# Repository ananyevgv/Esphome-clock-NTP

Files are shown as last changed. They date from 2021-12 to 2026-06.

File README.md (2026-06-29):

# ⏰ Умные часы с автоматической синхроизацией времени

[][license]
[][esphome-release]

[license-shield]: https://img.shields.io/static/v1?label=License&message=MIT&color=orange&logo=license
[license]: https://opensource.org/licenses/MIT
[esphome-release-shield]: https://img.shields.io/github/v/release/esphome/esphome?label=ESPHome&color=green&logo=esphome
[esphome-release]: https://GitHub.com/esphome/esphome/releases/

**Семейство умных часов** с синхронизацией времени, автоматической регулировкой яркости и расширенным функционалом — от датчиков до интернет-радио.

---

## 📸 Фотогалерея

| Версия 1 | Версия 2 | Версия 3 | Версия 4 |
|---|---|---|---|
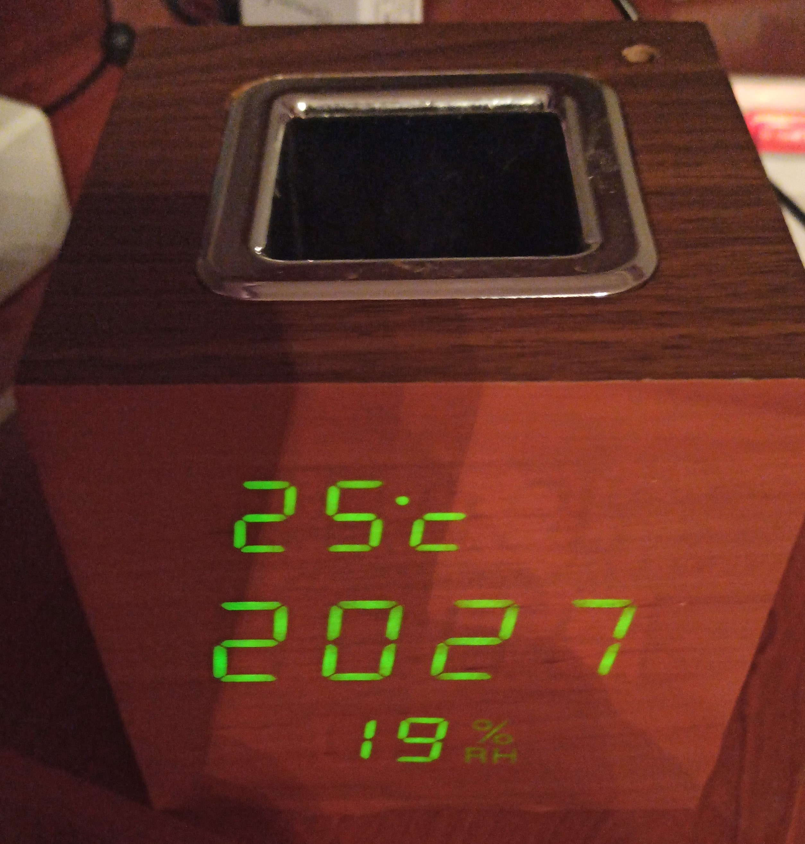
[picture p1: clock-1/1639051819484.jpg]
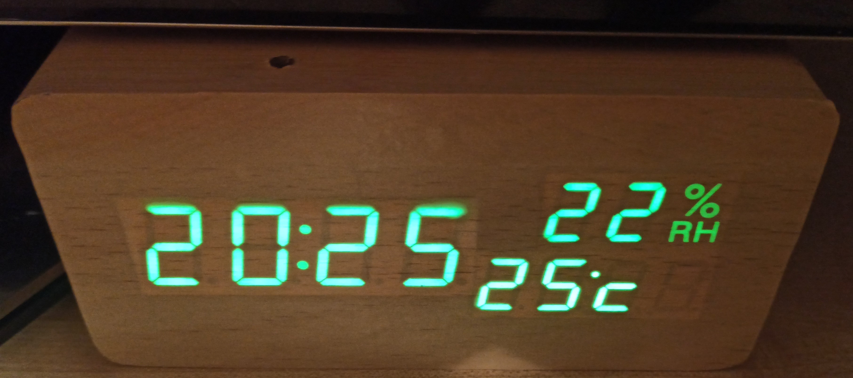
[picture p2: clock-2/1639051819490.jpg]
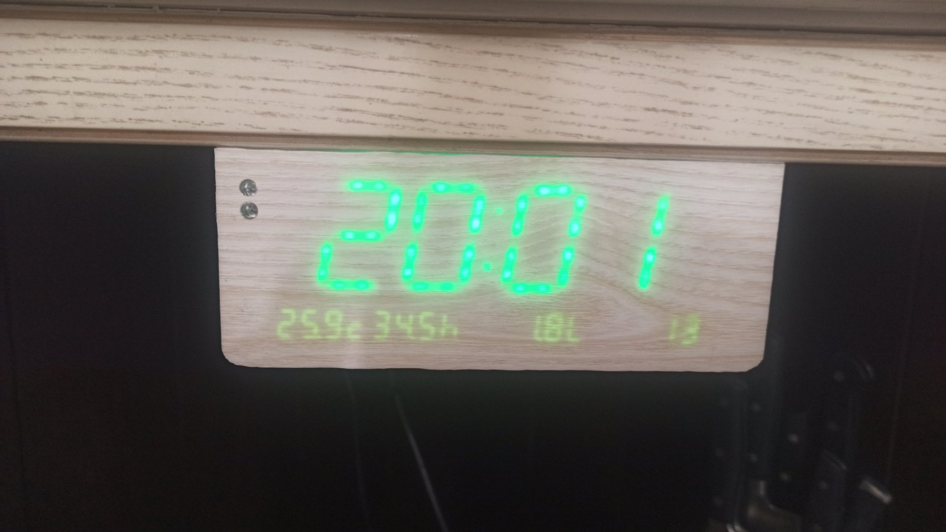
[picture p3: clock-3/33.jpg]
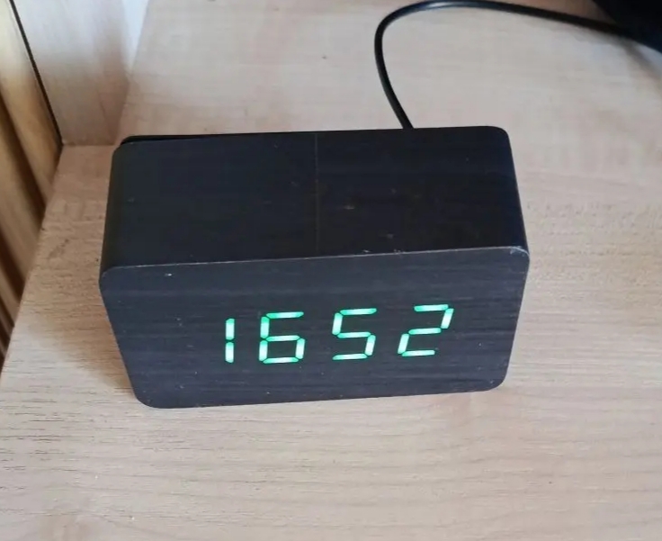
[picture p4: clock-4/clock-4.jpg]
|  |  |  |  |

---

## 🎯 Концепция

> **Всё в одном устройстве.**  
> Избавляемся от множества отдельных датчиков — все функции объединены в настольных часах.

Китайские готовые часы часто имеют дисплеи, установленные "вверх ногами".

---

## 📦 Версии

### 🔵 Версия 1
**Базовые часы + датчики + радио**

- ⏰ Синхронизация времени (NTP)
- ☀️ Автоматическая регулировка яркости
- 🌡️ Температура и влажность
- 💨 Качество воздуха
- 🌅 Положение солнца над горизонтом
- 📻 Интернет-радио 

**Дисплей:** 2 × TM1637 (7-сегментные, общий анод)  
*Особенность:* 5-й и 6-й разряды используются для индикации влажности

---

### 🟢 Версия 2
**Часы + датчики**

- ⏰ Синхронизация времени (NTP)
- ☀️ Автоматическая регулировка яркости
- 🌡️ Температура и влажность
- 🏠 Температура пола
- 📊 PZEM AC (мониторинг энергопотребления)
- 📡 ИК-пульт (управление ТВ)
- 🌡️ Атмосферное давление
- 🌅 Положение солнца над горизонтом

**Дисплей:** 3 × TM1637 (7-сегментные, общий анод)  
*Особенность:* 3-й разряд и DP 3-го модуля отображают значок влажности

---

### 🟡 Версия 3
**Часы для кухни**

- ⏰ Синхронизация времени (NTP)
- ☀️ Автоматическая регулировка яркости
- 🌡️ Температура и влажность
- 🏠 Температура пола
- 💧 Расход и температура фильтрованной воды
- 📡 ИК-пульт (управление ТВ)

**Дисплей:** 3 × MAX7219 (общий катод)  
*Особенность:* 7-сегментные индикаторы времени собраны из отдельных светодиодов в корпусе от старых часов VST

🔧 **Монтаж:** под кухонный гарнитур (3D-модель корпуса в папке `clock-3`)

⚠️ **Важно:** Питание на каждый модуль MAX7219 подключать **параллельно** напрямую от ESP, особенно "+" — последовательное подключение приводит к разной яркости!

---

### 🟣 Версия 4
**Минималистичные часы**

- ⏰ Синхронизация времени (NTP)

**Дисплей:** 1 × TM1637 (7-сегментный, 4-разрядный)

---

## ⏰ Будильник

Реализован с использованием компонента [`dynamic_on_time`](https://github.com/hostcc/esphome-component-dynamic-on-time) и аппаратной части:
- 🎵 DF-Player (MP3-плеер)
- 🌡️ BME-680 (температура, влажность, давление, качество воздуха)

📄 Конфигурация: [`smart-time.yaml`](./smart-time.yaml)

---

### Часы с перелистыванием цифр
Эффектная анимация смены цифр на дисплеях MAX7219.

📄 Конфигурация: [`max7219.yaml`](./max7219.yaml)

---

⚠️ **Важно:** Пин **D8** на Wemos D1 mini не использовать для подключения TM1637 и MAX7219!

---

## 🏠 Интеграция с Home Assistant

Для точной синхронизации времени рекомендуется установить аддон **Chrony**:


---

## 📄 Лицензия

Распространяется под лицензией **MIT** — свободно используйте, модифицируйте и вдохновляйтесь!

---

## ⭐ Поддержать проект

Если проект оказался полезным — поставьте ⭐ на GitHub!

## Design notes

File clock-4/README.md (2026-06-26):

# Четвертая версия





Умные часы с автоматической регулировкой яркости и синхронизацией времени через интернет.  
Собраны на базе **WEMOS D1 mini** с использованием **ESPHome**.

Часы
---

## 📋 Особенности

- ⏰ Отображение времени на 4-разрядном дисплее TM1637
- 🌐 Автоматическая синхронизация времени через NTP (SNTP)
- 🔋 Сохранение времени в RTC DS1307 при отключении питания
- ☀️ Автоматическая регулировка яркости по освещённости (фоторезистор)

---

## 🛠️ Аппаратная часть

### Компоненты
| Компонент | Модель | Назначение |
|---|---|---|
| Микроконтроллер | WEMOS D1 mini (ESP8266) | Управление |
| Дисплей | TM1637 (4-разрядный) | Отображение времени |
| RTC | DS1307 (I²C) | Ход времени |
| Датчик освещённости | Фоторезистор | Регулировка яркости |

⭐ Если проект полезен — поставьте звезду на GitHub!

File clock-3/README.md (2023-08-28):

Часы с синхронизацией времени и автоматической регулировкой яркости 
Третья версия
========================

Часы

Часы с синхронизацией времени и автоматической регулировкой яркости + датчики температуры, влажности, температуры пола, датчик расхода фильтрованной воды, ИК пульт (для включения ТВ) .

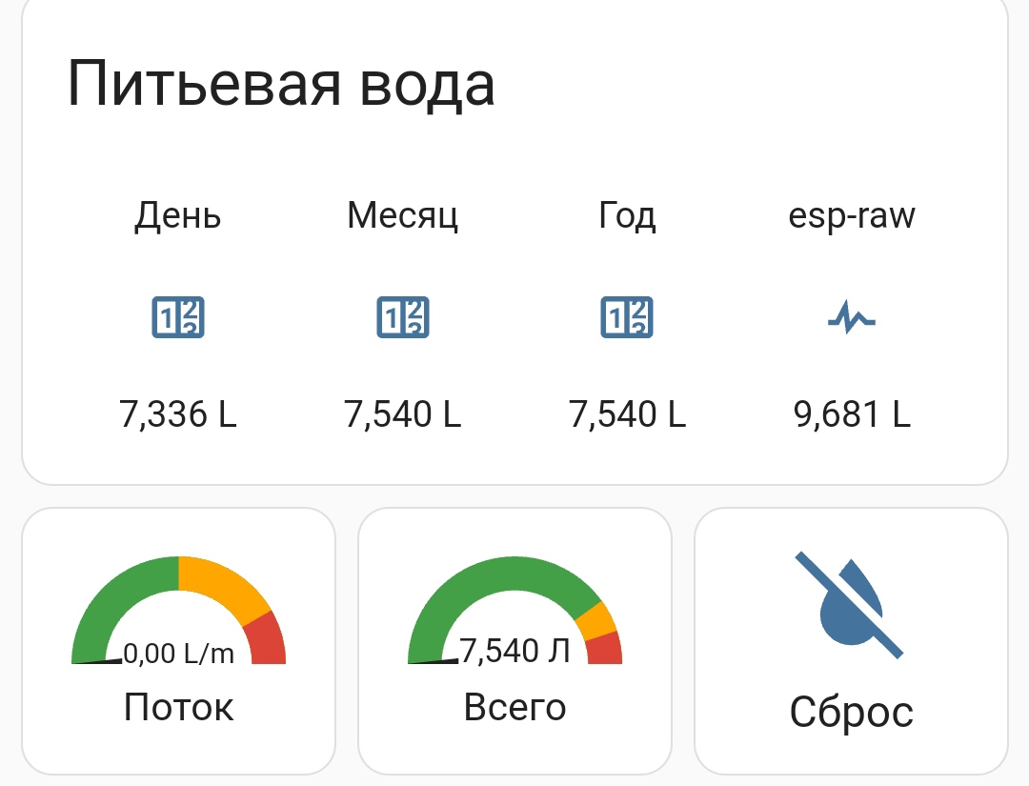
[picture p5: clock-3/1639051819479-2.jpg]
Фильтр


Дисплейный модуль построен на трех MAX7218 общий катод. Задуманы для крепления под кухонный гарнитур. 
7-ми сегментный 4 разрядный индикатор для отображения времени собран из светодиодов с использованием индикатора от старых часов VST. (Часы в процессе отладки). Питание на каждый модуль MAX7218 не стоит включать последовательно, лучше подключать на прямую от ESP особенно "+" (можно получить разную яркость).

Подавайте на счетчики 5 В и все будет ОК. При 3.3 даже без потока воды фантомные миллилитры.

https://github.com/ananyevgv/lovelas-HA

используется:

https://sprut.ai/article/bezumnyy-dom-delaem-protochnye-filtry-vody-umnymi

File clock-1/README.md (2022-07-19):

Часы с синхронизацией времени и автоматической регулировкой яркости 
Первая версия
========================

Часы с синхронизацией времени и автоматической регулировкой яркости + датчики температуры, влажности, качества воздуха, RF передатчик (в пути), + отображение нахождения солнца над горизонтом, интернет радио.

Дисплейный модуль построен на двух TM1637 т.к. в часах стоят 7-ми сегментные 4 разрядные индикаторы с общим анодом (MAX7218 общий катод). Для подключения индикатора влажности используется незадействованный 5 и 6 разряд TM1637. Значок влажности подключен 6 разряду и DP 2-го TM1637

Часы

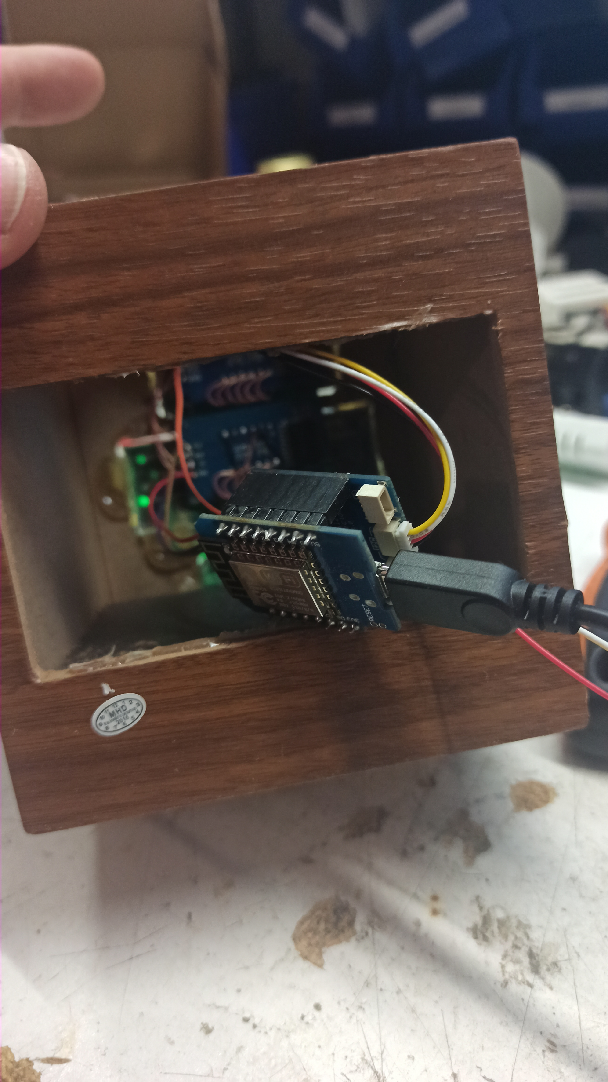
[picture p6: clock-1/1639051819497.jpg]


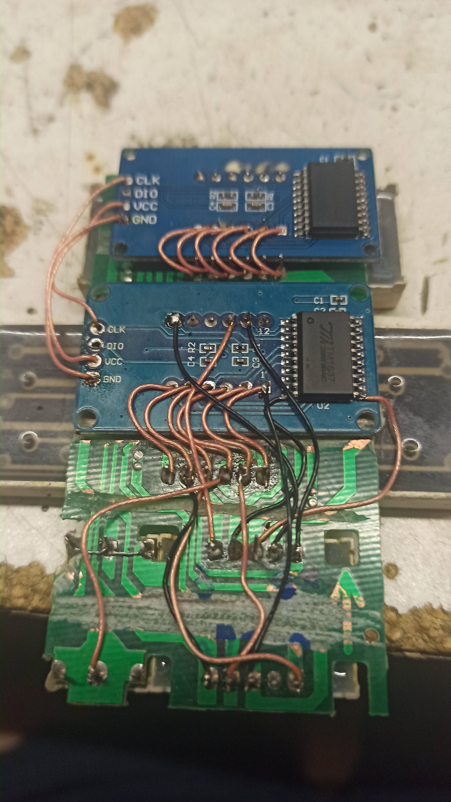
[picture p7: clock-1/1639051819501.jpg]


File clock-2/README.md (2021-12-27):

Часы с синхронизацией времени и автоматической регулировкой яркости Вторая версия
========================
Часы с синхронизацией времени и автоматической регулировкой яркости + датчики температуры, влажности, температуры пола, PZEM AC, ИК пульт (для включения ТВ), датчик давления + отображение нахождения солнца над горизонтом.

Дисплейный модуль построен на трех TM1637 т.к. в часах стоят 7-ми сегментные 4 разрядные индикаторы с общим анодом (MAX7218 общий катод). Значок влажности подключен к 3 разряду и DP 3-го TM1637.

Часы

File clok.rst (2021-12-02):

Часы с синхронизацией времени и автоматической регулировкой яркости
========================
.. seo::
    :description: Часы
    :image: cloc-f.jpg
    
Часы с синхронизацией времени и автоматической регулировкой яркости + датчики температуры, влажности, качества воздуха. В планах добавить интернет радио.

Сылки на компоненты
https://aliexpress.ru/item/1005002292394381.html (часы которые переделывал)
https://aliexpress.ru/item/32649468489.html (esp8266)
https://aliexpress.ru/item/32846977179.html (шилд)
https://aliexpress.ru/item/1005001391696335.html (AC-DC)
https://aliexpress.ru/item/32805933184.html (TM1638)
https://aliexpress.ru/item/4000055635431.html (AHT10)
https://aliexpress.ru/item/4000587263111.html (BH1750)
https://aliexpress.ru/item/4000252589302.html (RJ-12)
https://aliexpress.ru/item/32861772061.html (IR)

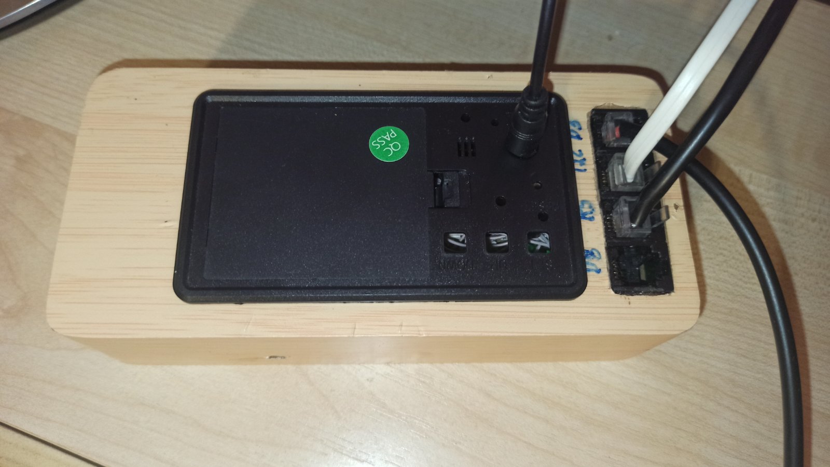
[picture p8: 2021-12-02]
clok-t.jpg

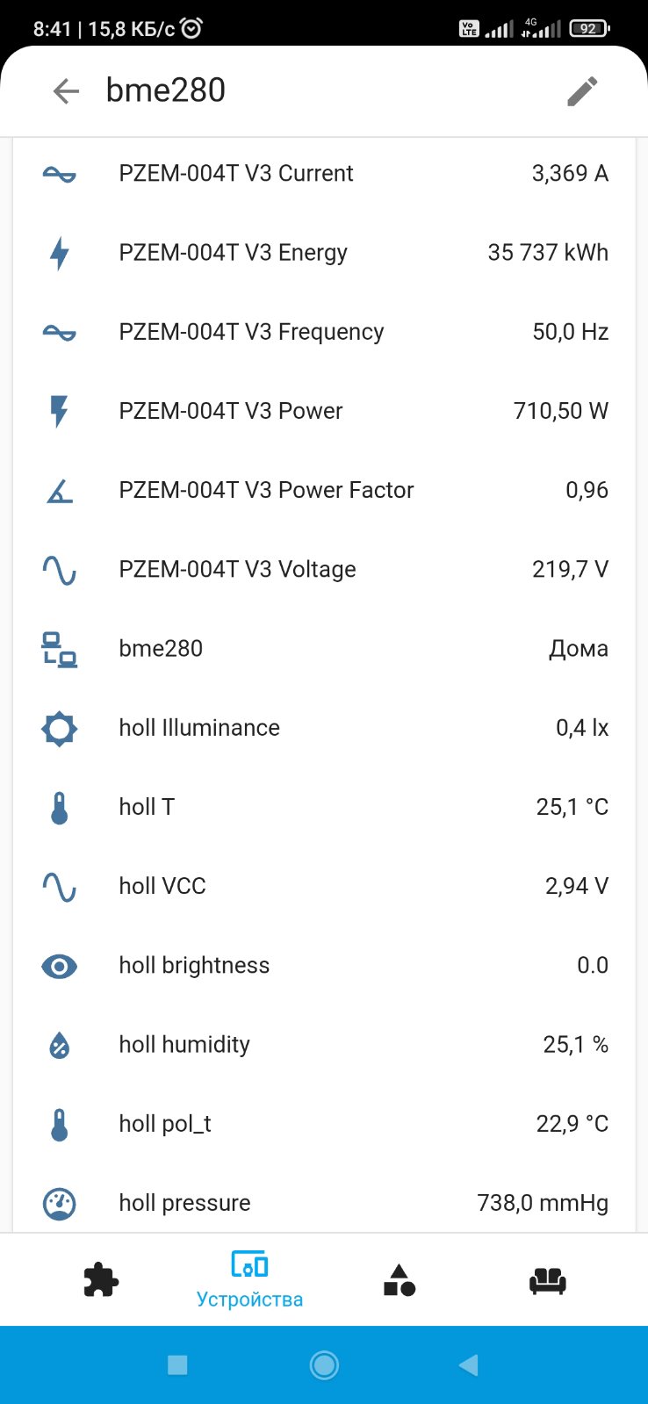
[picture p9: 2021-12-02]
dat.jpg

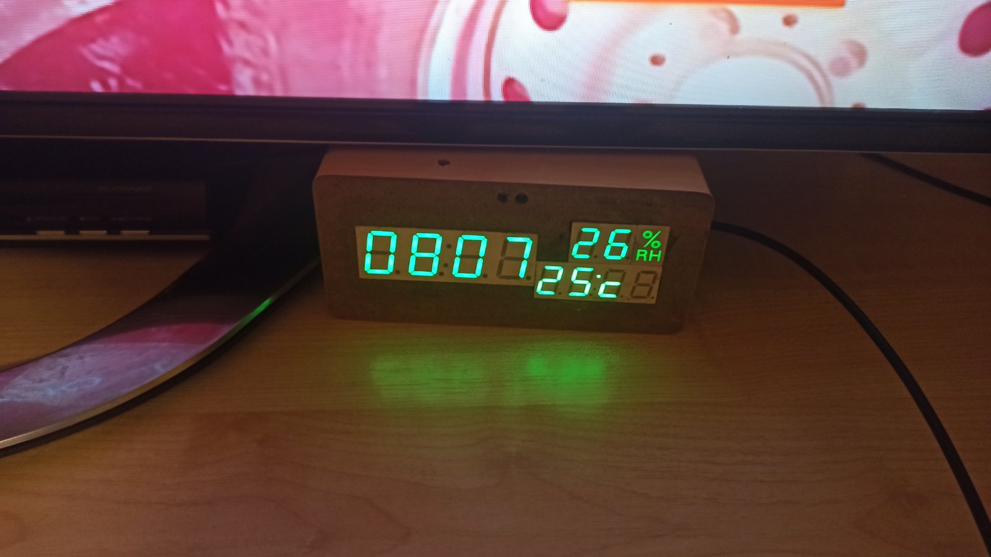
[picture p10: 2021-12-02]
cloc-f.jpg

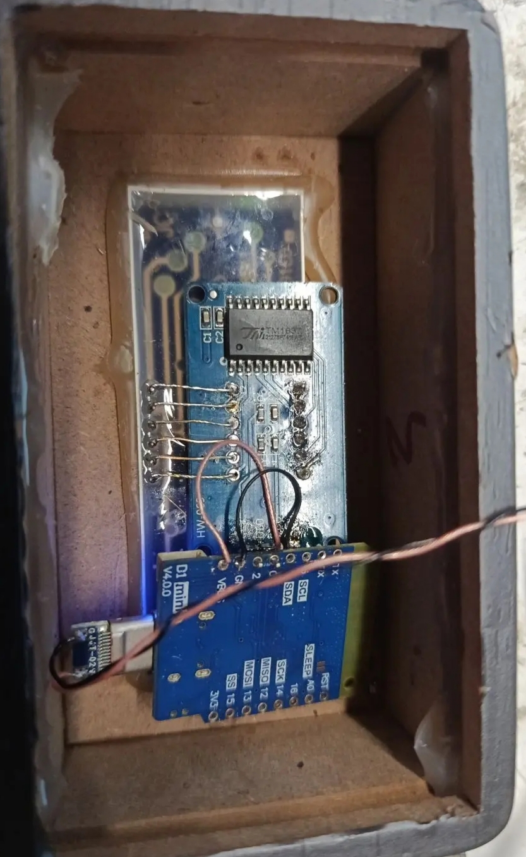
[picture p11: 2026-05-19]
clock-4/clock-4-0.jpg

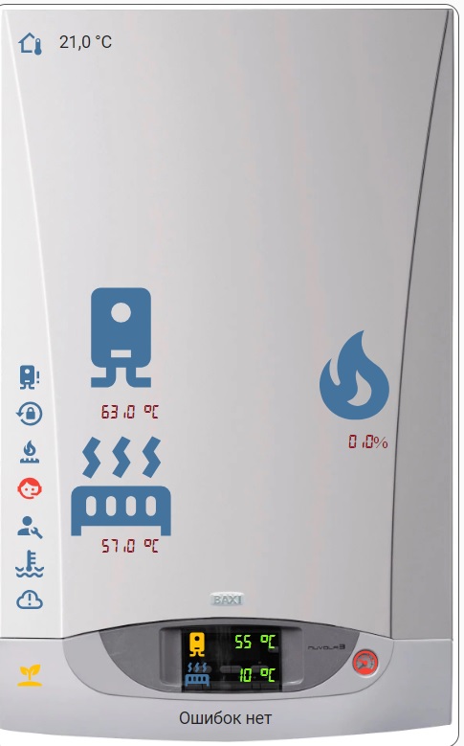
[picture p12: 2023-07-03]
clock-3/baxi.jpg

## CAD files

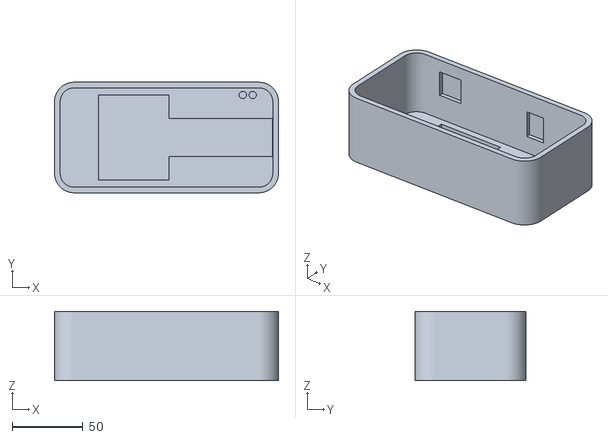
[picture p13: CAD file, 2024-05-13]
clock-2/часы-v3-Body.stl
158.0 x 78.0 x 49.0

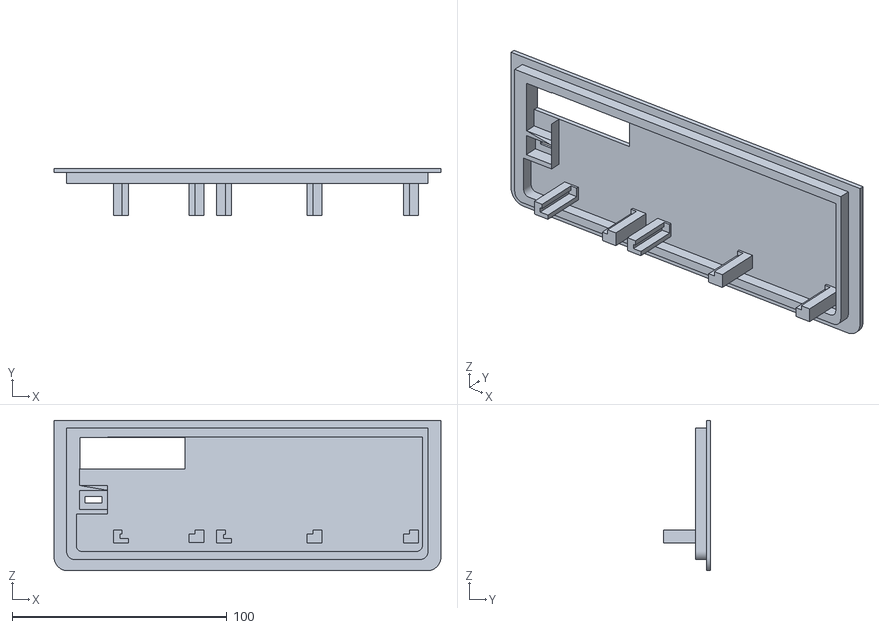
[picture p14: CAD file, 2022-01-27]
clock-3/Часы крышка-об-Body.stl
180.0 x 22.0 x 70.0

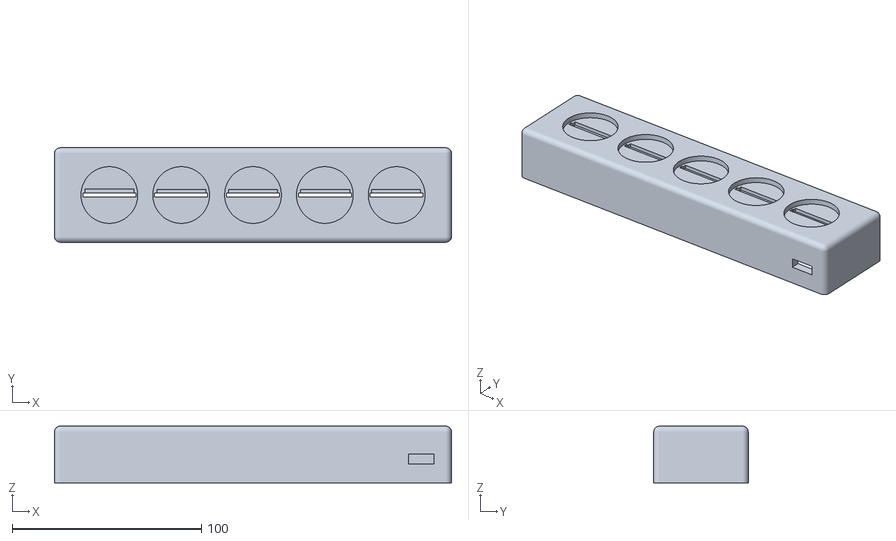
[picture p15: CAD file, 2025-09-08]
retro/retro 30мм тело.stl
210.0 x 50.0 x 30.0

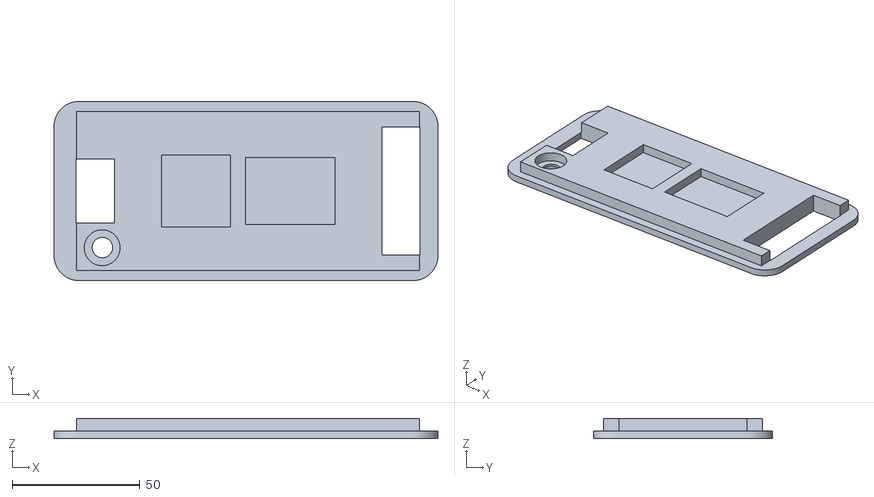
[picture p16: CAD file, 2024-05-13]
clock-2/часы-крышка-Body.stl
150.0 x 70.0 x 8.00

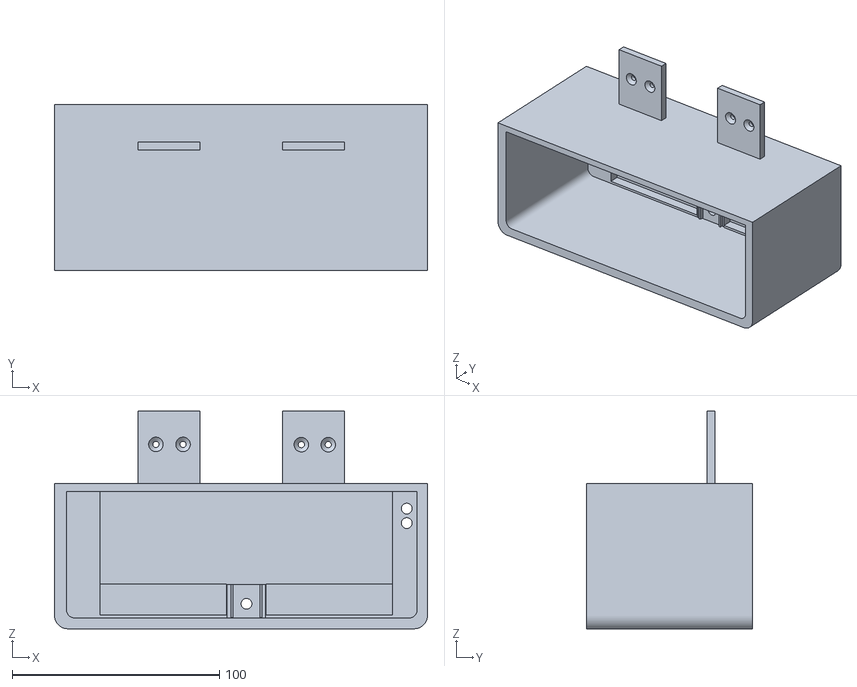
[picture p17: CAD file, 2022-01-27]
clock-3/Часы итог-Body.stl
180.0 x 80.0 x 105.0

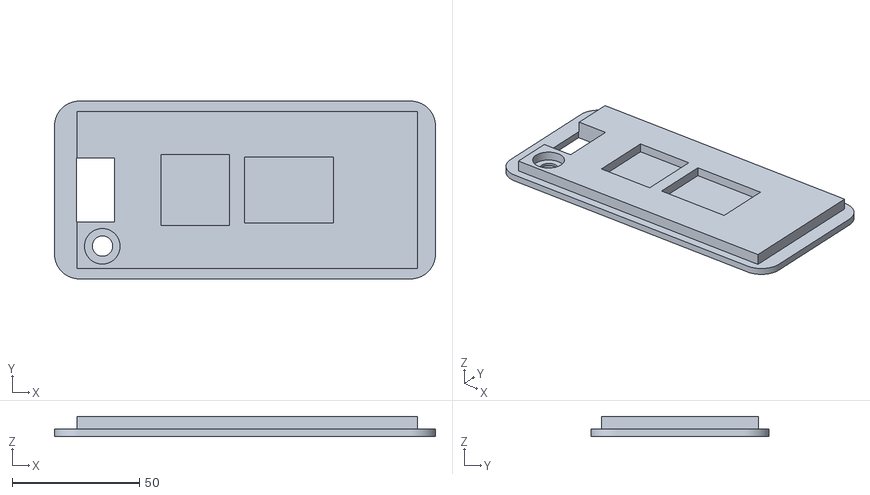
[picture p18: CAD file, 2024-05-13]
clock-2/часы-крышка-v2-Body.stl
150.0 x 70.0 x 8.00

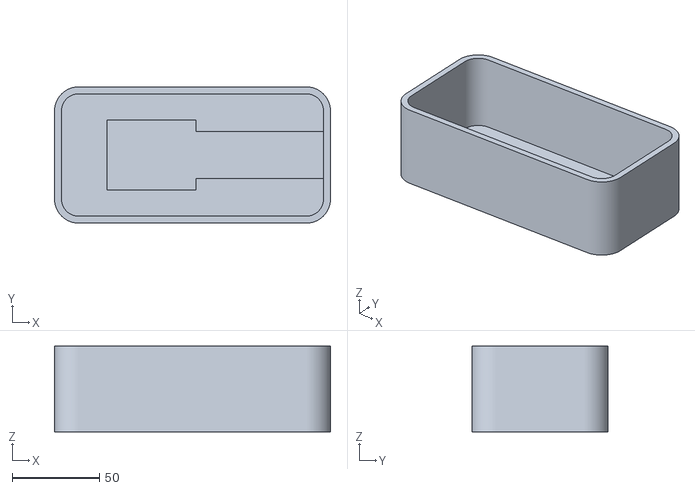
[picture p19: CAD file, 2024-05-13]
clock-2/часы.stl
158.0 x 78.0 x 49.0

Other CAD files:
retro/retro 32мм тело.stl

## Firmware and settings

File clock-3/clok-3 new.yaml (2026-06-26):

#######################################
##              WEMOS D1 mini        ##
##  |RS|       |#|     | 1|          ##
##  |A0|       |#|     | 3| W_OT     ##
##  |D0| clk   |#|     |D1| scl      ##
##  |D5| IR    |#|     |D2| sda      ##
##  |D6| mosi  |#|     |D3| dallas   ##
##  |D7| PM    |#|     |D4| cs       ##
##  |D8| R_OT  |#|     |GN|          ## 
##  |3V|       |#|     |5V|          ##
#######################################
substitutions:
  name: kitchen
  device_description: "Часы кухня"
  last_name: boiler
  
esphome:
  libraries:
    - Wire
    - "climateguard/ClimateGuard RadSens"
  includes:
    - RadSens1v2/_CG_RadSens.h  
  name: "${name}"
  comment: "${device_description}"
### BAXI ###
  on_boot:
    then:
      - delay: 2s
      - switch.turn_on: ch_2_enabled
      - switch.turn_on: dhw_enabled
      - number.set:
          id: dhw_num
          value:  54
### BAXI END ### 


esp8266:
  board: d1_mini

### BAXI ###  
external_components:
  source: github://ananyevgv/esphome-opentherm-khenderick
  components: [opentherm]
  refresh: 0s

opentherm:
  read_pin: D8 #D2
  write_pin: 3 #D1
### BAXI END ###  

api:
  password: !secret api_pass
#Включаем загрузку по воздуху
ota:
  password: !secret ota_pass

wifi:
  ssid: !secret wifi_ssid
  password: !secret wifi_password
  
logger:
   baud_rate: 0
#external_components:
#    source: github://pr#5477
#    components: [ max7219 ]
#    refresh: always

i2c:
   sda: D2
   scl: D1
   scan: true

spi:
  clk_pin: D0
  mosi_pin: D6
  
dallas:
  - pin: D3

remote_transmitter:
  pin: D5
  carrier_duty_percent: 50%

text_sensor:
  - platform: wifi_info
    ip_address:
      name: "${name} IP Address"
      icon: mdi:ip
    ssid:
      name: "${name} SSID"
      icon: mdi:access-point-network
    mac_address:
      name: "${name} Mac"
      icon: mdi:lan

### BAXI ### 
  - platform: template
    name: "${last_name} Ошибка котла"
    icon: mdi:water-boiler-alert
    lambda: |-
      uint8_t var = (id(oem_error).state);
      switch (var) {
        case 0: return std::string("");
        case 1: return std::string("E01 Отсутствие розжига");
        case 2: return std::string("E02 Сработал защитный термостат от перегрева");
        case 3: return std::string("E03 Сработал защитный датчик тяги");
        case 4: return std::string("E04 Частый срыв пламени");        
        case 5: return std::string("E05 Неисправность датчика отопления");
        case 6: return std::string("E06 Неисправность датчика контура ГВС");
        case 10: return std::string("E10 Неисправность датчика давления воды");
        case 11: return std::string("E11 Неисправность открытия входа внешнего программируемого датчика температуры (= 04)");
        case 12: return std::string("E12 Нет разрешения от дифференциального датчика гидравлического давления (прессостата)");
        case 13: return std::string("E13 Залипание контактов дифференциального гидравлического прессостата");
        case 18: return std::string("E18 Включено заполнение системы (замечание)");
        case 19: return std::string("E19 Неисправность при заполнения системы");
        case 25: return std::string("E25 Воздых в системе");
        case 35: return std::string("E35 Паразитное пламя (ошибка пламени)");
        case 80 ... 96: return std::string("E80-96 Ошибка сьемной панели)");
        case 97: return std::string("E97 Неправильная частота сети электропитания)");
        case 98: return std::string("E98 Проблема с контактами реле газового клапана, внутренняя ошибка");
        case 99: return std::string("E99 Проблема котактов реле, внутренняя ошибка");
        default: return std::string("Неизвестная ошибка");
      } 
### BAXI END ### 

sensor:
  - platform: custom
    lambda: |-
      auto rad_sens = new MyRadSens();
      App.register_component(rad_sens);
      return {rad_sens->IntensityDynamic_Sensor,rad_sens->IntensityStatic_Sensor, rad_sens->CurrentCPM_Sensor, rad_sens->MaxCPM_Sensor,rad_sens->Sensivity_Sensor};
    sensors:
      - name: "Dynamic intensity"
        id: dynamic_intensity
        accuracy_decimals: 1
        unit_of_measurement: μR/h
        state_class: measurement
        icon: mdi:radioactive
      - name: "Static intensity"
        accuracy_decimals: 1
        unit_of_measurement: μR/h
        state_class: measurement
        icon: mdi:radioactive
      - name: "Current CPM"
        accuracy_decimals: 1
        unit_of_measurement: CPM
        state_class: measurement
        icon: mdi:radioactive
      - name: "Max CPM"
        accuracy_decimals: 1
        unit_of_measurement: CPM
        state_class: measurement
        icon: mdi:radioactive
      - name: "Device Sensivity"
        id: sensivity
        state_class: measurement
        entity_category: diagnostic
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

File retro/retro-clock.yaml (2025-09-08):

# https://github.com/brettdottech/info-orbs
# https://github.com/esphome/feature-requests/issues/2917
# https://github.com/arendst/Tasmota/discussions/13161

###########################################################
##                    WEMOS S2 mini                      ##
##  |EN|       | 1|       |#|     |40|     |39| cs4      ##
##  | 3| cs0   | 2|       |#|     |38|     |37|          ##
##  | 5| cs1   | 4|       |#|     |36|     |35| scl      ##
##  | 7| clk   | 6|       |#|     |34|     |33| sda      ##
##  | 9| led   | 8|       |#|     |21|     |18| reset    ##
##  |11| cs2   |10|       |#|     |17|     |16| dc       ##
##  |12| cs3   |13|       |#|     |GN|     |GN|          ## 
##  |3V|       |14|       |#|     |15| led |5V|          ##
############################################################
#esp32:
#  board: lolin_s2_mini
#  framework:
#    type: esp-idf
#    sdkconfig_options:
#      CONFIG_ESP_CONSOLE_USB_CDC: y
############################################################
##                    WEMOS S3 mini                       ##
##  |EN|       | 1|        |#|     |33|     |43| cs4      ##
##  | 2| cs0   | 3|        |#|     |37|     |44|          ##
##  | 4| cs1   | 5|        |#|     |38|     |36| scl      ##
##  |12| clk   | 6|        |#|     |34|1    |35| sca      ##
##  |13| led   | 7|        |#|     |21|     |18| reset    ##
##  |11| cs2   | 8|2       |#|     |17|     |16| dc       ##
##  |10| cs3   | 9|3       |#|     |GN|     |GN|          ## 
##  |3V|       |14|        |#|     |15| led |5V|          ##
############################################################

substitutions:
  name: "clock"
  device_description: retro-clock

esphome:
  name: "${name}"
  platformio_options:
    board_build.f_flash: 80000000L
    build_flags: "-DBOARD_HAS_PSRAM"
    board_build.arduino.memory_type: qio_opi
    board_build.psram_type: opi
  on_boot:
    - priority: 500
      then:
        - light.turn_on:
            id: color_clock
            brightness: 100%
            red: 22%
            green: 93%
            blue: 7%
esp32:
  board: esp32-s3-devkitc-1
  cpu_frequency: 240MHZ
  framework:
    type: esp-idf

logger:
 
#-------------------------------------------
# Packages
#------------------------------------------- 
packages:
  wifi: !include packages/wifi.yaml
  device_base: !include packages/device_base.yaml
  # time: !include included/time.yaml
  web: !include included/web.yaml  

#-------------------------------------------
# PSRAM
#-------------------------------------------
psram:
  #mode: octal
  speed: 80MHz

#-------------------------------------------
# SPI
#-------------------------------------------
spi:
  clk_pin: 12 #36 #35  #st7789v SCL
  mosi_pin: 9 #35 #33 #st7789v SDA
 # interface: spi2

#-------------------------------------------
# FONT
#-------------------------------------------  
font:
  - file: "font/DSEG7Classic-Bold.ttf"
    id: SEG7
    glyphs: |-
      :.-0123456789
    size: 230
  - file: "font/DSEG14Classic-Bold.ttf"
    id: SEG14
    glyphs: |-
      :.-0123456789~
    size: 230

  - file: "font/nix-Ultra3.ttf"
    id: Ultra3
    glyphs: |-
      .-0123456789
    size: 230
    extras:
      - file: "font/nix-Ultra.ttf"
        glyphs: |-
          /
      - file: "font/DSEG7Classic-Bold.ttf"
        glyphs: |-
           :

  - file: "font/nix-Ultra.ttf"
    id: SET
    size: 320
    bpp: 8
    glyphs: |-
      =
    extras:
      - file: "font/DSEG7Classic-Bold.ttf"
        glyphs: |-
          1 2
#-------------------------------------------
# COLOR
#-------------------------------------------
color:
  - id: color_red
    hex: ff0000
  - id: color_blue
    hex: 2fc0ff
  - id: color_dark_gray
    hex: 333333
  - id: color_gray
    hex: 666666
  - id: color_green
    hex: 00ff00
  - id: color_yellow
    hex: e7c12c
  - id: black
    hex: e7c12c   

#-------------------------------------------
# OUTPUT
#-------------------------------------------
output:
  - platform: ledc
    pin: 13
    id: backlight_pwm

#-------------------------------------------
# LIGHT
#-------------------------------------------
light:
  - platform: monochromatic
    entity_category: config
    output: backlight_pwm
    icon: mdi:television-ambient-light
    name: "Display Backlight"
    id: backlight
    restore_mode: ALWAYS_ON

  - platform: esp32_rmt_led_strip
    entity_category: config
    icon: mdi:palette
    pin: 15
    num_leds: 1
    name: Color clock
    id: color_clock
    rgb_order: GRB
    chipset: WS2812
    #Ярко-зеленый
   # rmt_channel: 0
    on_state:
      - lambda: |-
          id(color_font) = Color(id(color_clock).remote_values.get_red()*255,id(color_clock).remote_values.get_green()*255 ,id(color_clock).remote_values.get_blue()*255 );
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

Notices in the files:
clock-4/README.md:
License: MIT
